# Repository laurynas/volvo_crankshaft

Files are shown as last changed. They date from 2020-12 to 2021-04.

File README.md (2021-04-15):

# Volvo V50 RTI + Crankshaft + Raspberry Pi + Arduino = ❤️

Run Android Auto on Volvo V50 RTI screen by retrofitting it with Raspberry Pi & [Crankshaft](https://getcrankshaft.com/).

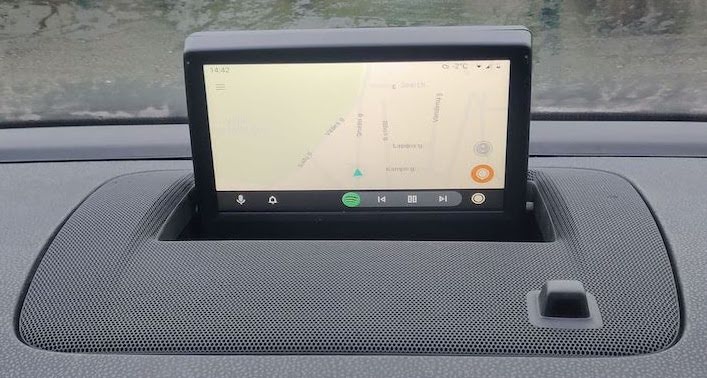
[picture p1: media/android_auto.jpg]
Working example (https://photos.app.goo.gl/vtM3ymQ5z1pJNeDw8)


[Photos and videos »](https://photos.app.goo.gl/vtM3ymQ5z1pJNeDw8)

## Features

- Steering wheel controls
- Open/close display when Android phone is plugged/unplugged

Missing / TODO:

- Automatic brightness adjustment using light sensor
- Sound output to the car stereo via RPi
- Microphone

I'm playing audio via Bluetooh audio adapter. 

## Ingredients

- Volvo V50
- Raspberry Pi 3B or later
- Arduino Pro Micro
- 6.5" AT065TN14 800x480 LCD + driver board. AT065TN14 exactly matches original RTI display dimentions (width x height). Also I found some alternatives - [thinner screen](https://www.aliexpress.com/item/4000329488912.html?spm=a2g0s.9042311.0.0.439c4c4dvR4vq8) and [smaller driver board with audio output](https://www.aliexpress.com/item/4001175095149.html?spm=a2g0s.9042311.0.0.439c4c4dvR4vq8).
- MCP2004 LIN bus transceiver. Or compatible like MCP2003, MCP2025.
- 12V -> 5V step down converter, like XL4005 or LM2596. I would choose 5amps instead of 3amps.
- [HDMI slim flat FPC cable](https://amzn.to/3hjNZCM)
- USB extension cable
- Micro USB to USB cable

## Overview

This is just a rough scheme showing how main components are connected. 

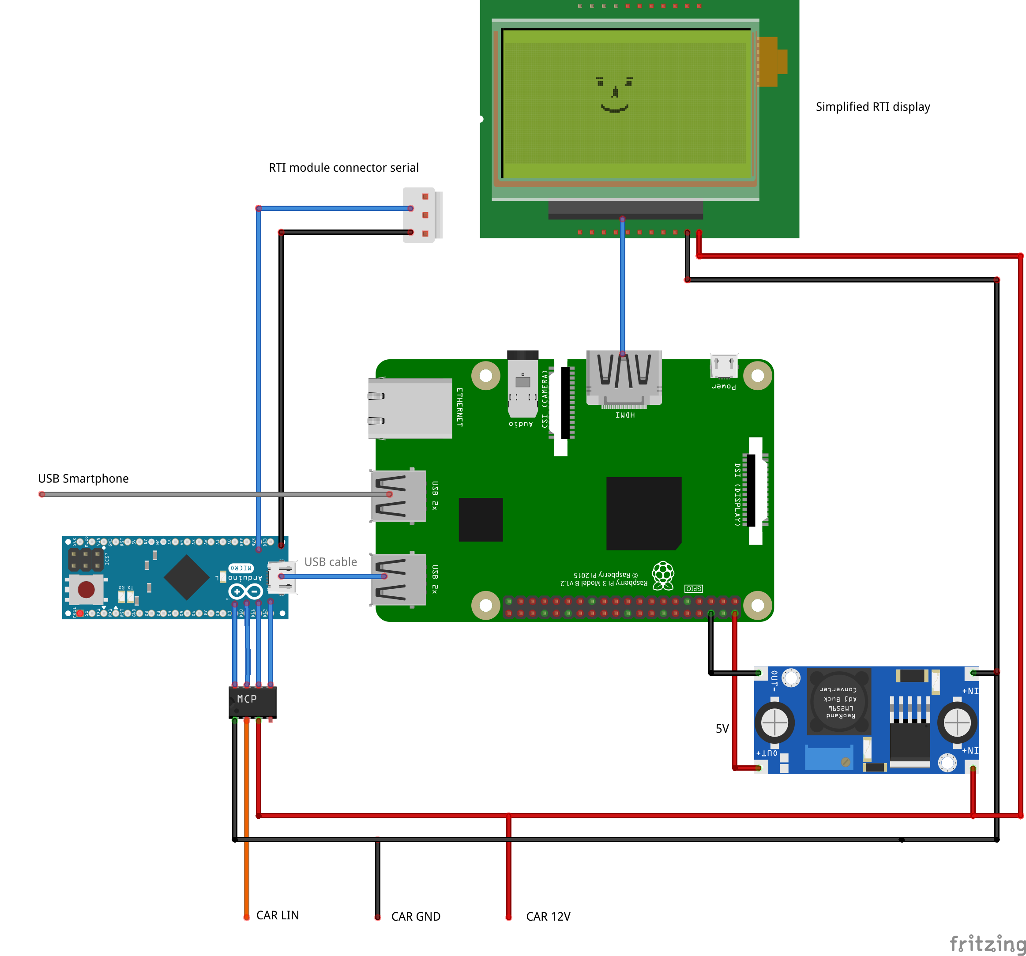
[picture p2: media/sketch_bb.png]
Rough scheme


Raspberry Pi is running [Crankshaft](https://getcrankshaft.com/) which enables Android Auto support.

Arduino is listening for steering wheel button events via [LIN bus](https://github.com/laurynas/volvo_linbus) transceiver. It converts these events to keyboard / mouse HID events and sends to Raspberry Pi via USB. Make sure you are using Arduino [hardware supported by the HID library](https://github.com/NicoHood/HID).

Via the same USB cable Raspberry Pi is sending phone state to Arduino.

Arduino is sending [serial events](https://github.com/laurynas/volvo#screen-control-signal) to Volvo RTI screen module and controls opening / closing of the screen.

Original RTI screen is replaced with AT065TN14 and connected to RPi using HDMI cable. Driver board is powered by 12V from RTI screen module.

RPi is powered from step down converter which converts 12V from the car to 5V.

## Configure Arduino

Build and upload [volvo_crankshaft.ino](volvo_crankshaft.ino) to Arduino.

## Configure RPi / Crankshaft

1. Connect to Crankshaft via [SSH](https://github.com/opencardev/crankshaft/wiki/Crankshaft-dev-mode).
2. Unlock readonly Crankshaft filesystem using `csmt` command line utility.
3. Copy files from [crankshaft/](crankshaft/) to RPi using SSH or just create them via the terminal. Place files under appropriate system folders and make `/opt/service_volvo_crankshaft.sh` executable.
4. Enable the serial service:

> systemctl enable volvo_crankshaft

> systemctl start volvo_crankshaft 

### Configure Crankshaft

Configure Crankshaft using Crankshaft UI -> Settings.

1. Enable keyboard controls - Arduino works as "keyboard" sending keyboard events to RPi.
2. Disable audio if you are playing audio via bluetooth adapter.

## Controls

1. When Android phone is connected, RTI screen should pop automatically and streering wheel controls can be used to navigate Android auto.
2. Clicking "Enter" on the steering wheel buttons when Android phone is disconneted will pop RTI screen and joystic will work as a mouse to navigate Crankshaft UI (you can use it to go to the settings). 
3. Long press of "Back" button will put the screen down.

## Tips

- MMM module is still receiving SWM events and occasionally might speak someting on your audio system :) To avoid that, you can disconnect it, but you need to put [optical bypass](https://allegro.pl/oferta/petla-swiatlowod-most-kabel-audi-seat-skoda-zestaw-9688273368) because otherwise radio wouldn't work. 

## Alternative - Using original RTI LCD display

I have also succeeded using original LCD display too. [More details in the wiki »](https://github.com/laurynas/volvo_crankshaft/wiki/Using-original-RTI-LCD-display).

## Links

- [Volvo V50 LIN bus reader](https://github.com/laurynas/volvo_linbus) - reading steering wheel controls
- [Volvo V50 RTI screen with Arduino controls](https://github.com/laurynas/volvo) - sending serial + VGA signals to original RTI screen
- [Volvo V50 RTI screen removal](https://www.youtube.com/watch?v=MJirMelq5ys)
- [Volvo V50 waterfall panel/radio removal](https://www.youtube.com/watch?v=Xo5NpBt04qs)
- [Volvo V50 glove box removal](https://www.youtube.com/watch?v=bLI-HLhO0_c) - if you decide to remove MMM module
- [Luuk Android Auto RTI project](https://luuk.cc/p/vD2f/Android_Auto_on_Volvo_RTI) - for Volvo S60, S80, V70, etc.

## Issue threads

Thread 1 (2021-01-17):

Volvo S80 2008

jmlgo, 2021-01-17:
Hi there!
First of all, congratulations for your great work! There are no so much options out there for our Volvos with RTI.
I would like to integrate this in my Volvo S80 II from 2008, that equips a DVD-based RTI system. I thinks is pretty similar to your V50 RTI.
I have a couple of doubts:

- Where is the most accesible LIN connector?
- Do you have a more detailed schematic?
- Do you think is it feasible to get rid of the Arduino?

Raspberry Pi has 2 available UARTs and multiple GPIOs, so it's possible to communicate with a external transceiver. The RTI module can be controlled as well, and the keyboard/mouse events can be emulated in python, for example, or can be even included in crankshaft directly (I have to check the sources).

Regards!

laurynas, 2021-01-18:
Hey @jmlgo,

Thanks, glad you liked the project!

I believe S80 has the same RTI screen, it just doesn't fold. I think same screen [replacement](https://www.aliexpress.com/item/4000329488912.html?spm=a2g0s.9042311.0.0.439c4c4dvR4vq8) should fit. I have recently found also a [smaller driver board](https://www.aliexpress.com/item/4001175095149.html?spm=a2g0s.9042311.0.0.439c4c4dvR4vq8) for the screen and it has audio output, which you might find useful.

Regarding LIN bus - I used the wire [from the ICM module](https://github.com/laurynas/volvo_linbus).

I'm just not sure if S80 also uses LIN bus for SWM (steering wheel) signals. There is [a project with S80](https://wot.lv/raspberrypi-powered-car-pc.html) by Latvian guy [Reinis](https://github.com/festlv). He used RPi to retrofit S80 RTI screen and he used CAN bus. Actually it took me quite a while and a lot of CAN bus sniffing until I realised that SWM uses LIN bus instead of CAN bus on my Volvo V50.

I haven't tried to go without Arduino as I reused it from the older project, but it would be nice to do without it. I think you would need 2 serial signals - 1 to send to RTI module, to lift the screen up, and second to talk to CAN bus. Or you can use some CAN header.

Let me know if you would succeed only with RPi, without Arduino. The less components - the better :)

Cheers!
Laurynas

laurynas, 2021-01-18:
Actually I have just checked S80 07- specs on Vida and seems that ICM is talking to SWM via LIN bus (just like V50).
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

Apparently old S80 version (till -06) used CAN bus for SWM.

jmlgo, 2021-01-18:
Thanks for the info!

Good find that driver board, there isn't too much space in my RTI display to fit new electronics.
I've checked Reinis project, and since he is using the previous version of S80 (P2), and I have the more recent P3, SWM will talk through LIN bus as well.

jmlgo, 2021-01-18:
Seems we were commenting at the same time haha
I've checked as well in VIDA with my VIN and indeed, it's talking through LIN bus.

I'll begin soon with this project and I'll try to get rid of the Arduino board to integrate everything with the Raspberry Pi and a external transceiver. I'll be back with an update when I get the parts and can begin with the firsts tests.

Crankshaft and your project are excellent work. There are almost no afordable options for our cars out there to integrate a moderm solution, and even less to do it with Android Auto. Hope I can contribute with some new features.
Regards!

laurynas, 2021-01-18:
Cool! Good luck with your project and let me if you will be able to get rid of Arduino :)

Pabiloboss, 2022-06-07:
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

Hi @jmlgo
I´m wondering if you finally finished your project. I also own an S80 P3 (2011) and having some issues with the low speed can bus for the RTI movement. I monitored that bus and guessed RTI´s ID is 0x07A and have the proper data for raising, stand by, reverse, etc, but when I start throwing those codes in a can bus with just the RTI and my mcp2515 module nothing happens. My module sends the messages correctly, RTI reacts to the can bus (short noise when plugging, like in the car), volts are good (2.7 H and 2.3 L) but RTI do nothing.

Any comment would be more than appreciated!

jmlgo, 2022-06-07:
Hi @Pabiloboss,
I couldn't go ahead with the project at that time due to problems with a faulty screen that I got on Aliexpress.
I had all the setup working over the table with the LIN bus for the SWM, but I never removed the front display from the car so I've never tested the rising command.

Did you got the can-bus frames that the display receives during the normal operation, since you turn on the contact?
Maybe it just needs an init command before the rising command.
I'd be glad if you share that can-bus frames.

Another posibility, since you say it seems to react to the rising command, is that you are not providing enough power to rise the display.

Pabiloboss, 2022-06-07:
@jmlgo , yes I have all can frames and have 2 ids "reacting" when I press enter on the SWM. Also have lin frames, the only thing I'm missing is how to move the screen.
I'm out now but as soon as I arrive home I'll get in touch with you.
So glad we can collaborate!

Pabiloboss, 2022-06-08:
@jmlgo there is no private messaging(I forgot), so give me your email and we can share what we both have and luckily we can create a new repository with the finished job

pavlickk, 2022-08-30:
hello!
any idea, what does it take to control the screen on P3?
ive tried arduino with attached code, but nothing happens

jmlgo, 2022-08-30:
P3 has a low-speed can-bus dedicated for some systems, including the front display.
@Pabiloboss is currently trying to implement this.

AdoDyzas, 2024-03-18:
Hi everybody,

I have RTI P3 from XC70. But can't find any info about how to control RTI display (turn on and rise). As I figure out that all communication goes via CAN communication.  Maybe anyone figure out it? I new with programing so it's not so easy for me.

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

Miziol, 2024-09-19:
Dear @y0grt @Pabiloboss have you got some info about CAN bus command which can open and close the screen?

@AdoDyzas may be you found some info about CAN bus which can help us

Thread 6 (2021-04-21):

Without Steering wheel controls

DaveH240180, 2021-04-21:
Hi Laurynas,

I have came across your build while searching for this exact crankshaft type build, I came across one that didn't really say much with regards to where you place certain code yours is much more informative

My question is this is there any way to modify the code so i dont have the SWC options as the screen i am going to be using has touchscreen functionality, I have a rpi 3b+ and a arduino nano also the latest version of crankshaft all up and running just waiting on a screen to arrive as i am retrofitting a screen into the car as it didn't come with navigation

Any help on this would be greatly appreciated

thanks
Dave

laurynas, 2021-04-28:
Hi Dave,

you you don't need steering wheel controls and use touchscreen instead, it should just work. Actually you could drop Arduino & LIN bus transceiver in this case. You could just send serial signal from RPi to the RTI screen when you would need to raise the screen.

So, you wouldn't need Arduino part at all in this case, but you would need to implement serial signal sending on RPi.

Cheers!
Laurynas

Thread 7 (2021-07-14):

Wiring

tequitotortilla, 2021-07-14:
Hi Laurynas!

Such a great project, it has been great so far!
I'm currently wiring up my pro micro to everything. I already tested it and had the same results as shown in your YT video where you can see the screen getting up. With that project, the RTI is connected using the Tx pin of the pro micro. (had to swap serial with serial1 because I cheaped out and did not get the Arduino version).
Now when looking at the .ino file in this repo I get a little confused; please correct met if i am wrong.
I deduct from the code that the RTI display is now wired via pin 10 with ground still to ground.
Now I think the MCP2003 Rxd pin should be connected to the Pro Micro Tx pin.
And the MCP Txd pin should be connected to the Pro Micro Rx pin.
MCP2003 CS pin to 15 and with no FAULT pin on the 2003, I think pin 17 (RX led) is not connected.
Wiring the Pi directly to acc power in the car is a bad idea since you will be pulling the plug instead of a graceful shutdown. I see in the .ino script that you have implemented a Pi power button too. Which I assume turns the Pi on and off so it can stay wired to the battery 12V. I am not sure how this is connected to the Pi? I was hoping you could help me out here.
I will wire the screen driver board to acc power since it does not need to be powered when the car is off.

Thank you for sharing this amazing project for everyone. Kind regards from Amsterdam,
Niels

tequitotortilla, 2021-07-20:
Update:
I've connected everything up and installed it in the car. Unfortunately the steering wheel buttons are not working. I've wired my MCP2003
Vbb -> 12v
Vss -> ground
Lbus -> Car lin bus (pin 2 from media system)
CS -> 5v powered pin on the arduino
Rx -> arduino Tx
Tx -> arduino Rx

If I understand the documentation of the mcp correctly this should be working.

laurynas, 2021-07-29:
Hi @tequitotortilla, sorry for delayed answer.

The pin numbers are configured in the arduino source code:
https://github.com/laurynas/volvo_crankshaft/blob/main/volvo_crankshaft.ino#L17

You can also try the this simple debugger:
https://github.com/laurynas/volvo_linbus

I was doing my project on Volvo V50, I'm not sure if all models use the same codes. I think other models, like S80 uses CAN-Bus for steering wheel buttons: https://luuk.cc/p/vD2f/Android_Auto_on_Volvo_RTI

Erik187v, 2022-02-01:
Wiring the Pi directly to acc power in the car is a bad idea since you will be pulling the plug instead of a graceful shutdown. I see in the .ino script that you have implemented a Pi power button too. Which I assume turns the Pi on and off so it can stay wired to the battery 12V. I am not sure how this is connected to the Pi? I was hoping you could help me out here. When the Pi is shut off is will not give power to usb (right?) so how is the Pro Micro powered to receive the signal to turn the Pi on? I will wire the screen driver board to acc power since it does not need to be powered when the car is off.

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

Did you solve how the power to the rpi and arduino is controlled?

From what i can tell the arduino starts and shutsdown the rpi on ignition but i have the same question as you do, if the arduino is powered by the rpi how does it start the pie?

what am i missing?

kind regards

tequitotortilla, 2022-02-01:
Hi Erik, I did solve the issue in the end by just shutting down the power on the RPi with the ignition. It is not very graceful but in one of the processes the RPi was set to only read not write on storage. If systems get corrupted with ungraceful shutdowns it is mostly because the system was interrupted while (re)writing system files. Because the system is read only that does not happen and it reduces the chance of a corrupted system. Mine is stull running after 6 months at least. Although I never got the steering wheel buttons to work :(

Lukasguy, 2022-02-08:
Did you ever try connecting the Rxd pin of the MCP to the Rx input of the arduino? Rxd stands for Rxdevice (I think) and according to the datasheet it's an output. Thus Rxd has to be connected to Rx and Txd has to be connected to Tx (which is confusing because normally it's the other way around). The typical applications section 1.4 also shows this. I would test & verify this myself but I'm still in the testbench phase, though I will run into this later.

Also thank you Laurynas for this project! It has been a huge inspiration for me to integrate Carplay into my C30!

Erik187v, 2022-04-12:
> Hi Erik, I did solve the issue in the end by just shutting down the power on the RPi with the ignition. It is not very graceful but in one of the processes the RPi was set to only read not write on storage. If systems get corrupted with ungraceful shutdowns it is mostly because the system was interrupted while (re)writing system files. Because the system is read only that does not happen and it reduces the chance of a corrupted system. Mine is stull running after 6 months at least. Although I never got the steering wheel buttons to work :(

Its figured it out, he left out the transistor and some resistors acting as a power switch,  shorting pin 5 and 6 to turn on the PI when its off and using a shutdown script turning it off gracefully with the pin is high (stays low when ignition is on because the pins is shorted). I used a BC574 and 2x 1k ohm resistors to act as a switch. instead of using the output from the arduino you could hook it upp directly to the cars ignition as i did with a regulator in between!

Script example shutdown after 15min when iginition goes off and cancel if it goes on before (I did some modifications where i turn off the LCD directly and on again if ignition goes live so if i stop for gas i dont have to wait for the pi to boot).
#! /usr/bin/env python

import time
import RPi.GPIO as GPIO
import subprocess
GPIO.setmode(GPIO.BCM)
GPIO.setwarnings(False)

pin = 3 // pin 5  is gpio 3

GPIO.setup(pin, GPIO.IN, GPIO.PUD_UP)

while True:
    button_state = GPIO.input(pin)
    if button_state == GPIO.HIGH:
      subprocess.call(['shutdown', '-h', '15'], shell=False)
      print ("Ignition off")
    else:
      subprocess.call(['shutdown', '-c'], shell=False)
      print ("Ignition on")
    time.sleep(5)

Regulator 12v -> 5v:
https://www.amazon.se/ARCELI-AMS1117-3-3-sp%C3%A4nningsregulator-avst%C3%A4ngningsbar-str%C3%B6mf%C3%B6rs%C3%B6rjningsbuljong/dp/B07MY2NMQ6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

Erik187v, 2022-04-12:
> Did you ever try connecting the Rxd pin of the MCP to the Rx input of the arduino? Rxd stands for Rxdevice (I think) and according to the datasheet it's an output. Thus Rxd has to be connected to Rx and Txd has to be connected to Tx (which is confusing because normally it's the other way around). The typical applications section 1.4 also shows this. I would test & verify this myself but I'm still in the testbench phase, though I will run into this later.
>
> Also thank you Laurynas for this project! It has been a huge inspiration for me to integrate Carplay into my C30!

Im also installing Carplay on my C30 using Open Auto. But the biggest problem for us is that we need to keep the original LCD! But not anymore, hit me up if u want the option to stream the ICM instead, i'd be happy to help out!

Bye bye crappy LCD :
https://www.youtube.com/shorts/r7sB46zHM6A

laurynas, 2022-04-13:
Hey, sorry, missed most of the discussion :) Just my 5 cents - I'm using my solution almost daily. There is no graceful shutdown, just the hard power off. Works fine for more than a year.. :)
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
Erik187v, 2022-05-17:
I dont use the rti part since i replaced the original icm so i cant help with that in sorry.

as long as the wires are right u could debug with any linbus reader. There is plenty out there with better support! As long as u have it reading linbus u can work on the software for the keyboard ur self. Its the best way to tackle this. I decided to use another linbus frame and built my kerboard handeler my self and just skipped the rti part.

but to make it easier for u i would suggest that. Try another clean linbus reader slave source and build upon that instead

Pabiloboss, 2022-05-17:
> I dont use the rti part since i replaced the original icm so i cant help with that in sorry.
>
> as long as the wires are right u could debug with any linbus reader. There is plenty out there with better support! As long as u have it reading linbus u can work on the software for the keyboard ur self. Its the best way

Erik187v, 2022-05-18:
> > I dont use the rti part since i replaced the original icm so i cant help with that in sorry.
>
> That's dreat! That was my first idea, to replace the icm, but I have the premium sound system which is dawm good but, unluckily, all configurations go through the original icm, so I ended up just replacing the Navi...

I still use the original amplifier and i kept the icm module ans hijack the lcd signal and display it as a overlay on my setup. I can still use the original configuration and menus i just dont have the old lcd

Pabiloboss, 2022-05-18:
> I still use the original amplifier and i kept the icm module ans hijack the lcd signal and display it as a overlay on my setup. I can still use the original configuration and menus i just dont have the old lcd
>
> https://youtu.be/h19fsgQmMdM

Simply amazing! Great job! I look forward to seeing your progress! Even though it´s not my goal (I rather like navi on top of the dashboard), if you´d like to test your project on a S80 P3 just let me know. I´m more than willing to collaborate, @Erik187v

Pabiloboss, 2022-05-24:
Guys, I had the suspicion, but now I´m sure. In P3 configuration, at least my S80´s, rti screen is managed via low speed CAN BUS. I've been through VIDA and it is crystal clear. So now I´ll make my own research and CAN sniff so I can modify laurynas code accordingly. I´ll let you know when sorted out.

jacoqq, 2025-03-30:
Hi,
First of all, thank You Laurynas, great job.
I'm stiil confused with wiring. Is there anyone who could make a sketch with the exact connection? According to https://photos.google.com/share/AF1QipMlcIAPwL2aJV3OyTbHpNdbMLiskVYX2OP57K1AqoD92cU2QgqgX4AXHpQ2rx2HcA/photo/AF1QipMFsHBVfw-tWltWxdz219b_BTAqYg37RJw1u_JB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 there are a few more resistors and I have no idea how to connect it all together.
I would be extremely grateful for some guidance.
My spec:
Volvo S40
RPi 3 B+
Arduino Pro Micro (Leonardo)
MCP 2004A-E/P

laurynas, 2025-04-01:
Hey @jacoqq ,

I'm glad you find this project useful and doing DIY yourself 👍 Unfortunately I already sold my Volvo so I don't remember exact wiring, but the rough idea (without exact pins) I've described here:
https://github.com/laurynas/volvo_crankshaft?tab=readme-ov-file#overview
also this could be useful, just to understand MCP first, before building full solution:
https://github.com/laurynas/volvo_linbus

I agree that in the photo you referenced, there are more components visible, like a button and transistor. I think I used it for raspberry pi power button via GPIO:
https://github.com/laurynas/volvo_crankshaft/blob/main/volvo_crankshaft.ino#L22
I think the physical button is not needed, I probably just used it for testing.

Sorry, I don't remember in more details, but I think from this rough charts it should be possible to build a working solution (it was working and I used it for years). Just experiment with MCP connecting it to Arduino first via serial, and also experiment with the screen mechanism connecting it via serial. It takes some time to figure out, but once you do - everything should become quite simple.

jacoqq, 2025-04-04:
That explain me a lot and now everything seems to be clear. I'm still waiting for my MCP and after that I'm getting down to work. Again thanks Laurynas, I owe You a huge beer :)

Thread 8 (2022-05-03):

Arduino - class LinFrame 'pop_byte' error

cavewd, 2022-05-03:
Hi! i have been following your page to this project myself and it has been very helpful. I'm new to both raspberry and Arduino, but i have not been able to fix this error through using your write up. I'm really hoping you'll be able to help me

I'm running IDE version 1.8.19, i have tried restarting building the .ino file twice but keep getting to this error, i feel like i might be missing a .h file or another library as IDE is not colouring all the code like it is seen on github.
sorry for making another issue, your work has been very helpful (i am absolutely a Linux/C noob!) but i cant get around this error
thanks for your time

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
e

Lukasguy, 2022-05-06:
Hi,  not the creator of this project but maybe I can help.

In the pictures you posted I can't see the include for lin_frame.h: #include "src/lin_frame.h"
This is very important, otherwise lin_frame class and it's functions can not be found.

I was also wondering why the SoftwareSerial.h file is in the same folder as the .ino file. If your arduino IDE can not find the software serial library then you should install it using the library manager from the IDE:
https://docs.arduino.cc/software/ide-v1/tutorials/installing-libraries

Perhaps you should start from the original .ino first and test if everything works. Then start modifying it to add whatever you need.

Good luck!

cavewd, 2022-05-09:
Hi All. this was an error on my part for being new to github!
i had copied the code in each file trying to replicate Laurynas work, when i should have downloaded it as a zip and then run the .ino file. There is no issue with the project.
For people like me with no experience:
Make sure to find the correct software for the pro micro board(Sparkfun pro micro) online and add to the arduino coding environment, you wont find the right board without it. Similarly, make sure the cable used will transfer data not just power else you'll never find the right port or upload to the board.
If you're new to Linux, make sure to look up Linux file system hierarchy as its useful when navigating to the correct file area for crankshaft install, how to enter terminal on crankshaft (dev mode) and commands like: cd, ls (LS), gitclone, rasp config, chmod -x. Use a raspberry pi software loader to put crankshaft on your pi, loads of videos online for this.
and a thank you to Lukasguy, your comment about the original .ino file meant i realised where i had gone very wrong :))

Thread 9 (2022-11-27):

Only steering buttons

OziMasterPL, 2022-11-27:
Thank You for this project.
I have Openauto Pro not Crankshaft
I need use arduino only for  steering buttons emulation without mouse mode and open/close rti screen.
How modify code for this.

How do it?

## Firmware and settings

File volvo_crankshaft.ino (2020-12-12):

//Lbus = LIN BUS from Car
//Vss = Ground
//Vbb = +12V

// MCP2004 LIN bus frame:
// ZERO_BYTE SYN_BYTE ID_BYTE DATA_BYTES.. CHECKSUM_BYTE

#define DEBUG true

#include "Keyboard.h"
#include "Mouse.h"
#include "SoftwareSerial.h"

// https://github.com/zapta/linbus/tree/master/analyzer/arduino
#include "src/lin_frame.h"

#define CS_PIN 15
#define RX_LED 17
#define RTI_RX_PIN 16
#define RTI_TX_PIN 10

#define PI_POWER_BUTTON_PIN A3
#define PI_POWER_BUTTON_DURATION 100
#define PI_TIMEOUT 30000

#define ON_CLICK_DURATION 100
#define OFF_CLICK_DURATION 3000 // how long to hold "back" button to turn off

#define CLICK_TIMEOUT 300

#define HEARTBEAT_TIMEOUT 2000
#define RTI_INTERVAL 100

#define MOUSE_BASE_SPEED 8
#define MOUSE_SPEEDUP 3

#define SYN_FIELD 0x55
#define SWM_ID 0x20

// Volvo V50 2007 SWM key codes
//
// BTN_NEXT       20 0 10 0 0 EF
// BTN_PREV       20 0 2 0 0 FD
// BTN_VOL_UP     20 0 0 1 0 FE
// BTN_VOL_DOWN   20 0 80 0 0 7F
// BTN_BACK       20 0 1 0 0 F7
// BTN_ENTER      20 0 8 0 0 FE
// BTN_UP         20 1 0 0 0 FE
// BTN_DOWN       20 2 0 0 0 FD
// BTN_LEFT       20 4 0 0 0 FB
// BTN_RIGHT      20 8 0 0 0 F7
// IGN_KEY_ON     50 E 0 F1

#define JOYSTICK_UP 0x1
#define JOYSTICK_DOWN 0x2
#define JOYSTICK_LEFT 0x4
#define JOYSTICK_RIGHT 0x8
#define BUTTON_BACK 0x1
#define BUTTON_ENTER 0x8
#define BUTTON_NEXT 0x10
#define BUTTON_PREV 0x2

#define CRANKSHAFT_ANDROID_CONNECTED '+'
#define CRANKSHAFT_ANDROID_DISCONNECTED '-'

short rtiStep;

SoftwareSerial rtiSerial(RTI_RX_PIN, RTI_TX_PIN);

LinFrame frame = LinFrame();

unsigned long currentMillis, lastHeartbeat, lastPiHeartbeat, lastRtiWrite, buttonDownAt, lastButtonAt, lastJoysticButtonAt;
bool on = false;
bool android = false;
bool manualOn = false;
byte currentButton, currentJoystickButton;
int mouseSpeed = MOUSE_BASE_SPEED;

void setup() {
  pinMode(PI_POWER_BUTTON_PIN, OUTPUT);
  analogWrite(PI_POWER_BUTTON_PIN, 0);

  pinMode(RX_LED, OUTPUT);

  pinMode(CS_PIN, OUTPUT);
  digitalWrite(CS_PIN, HIGH);

  Serial.begin(9600);
  Serial1.begin(9600);
  rtiSerial.begin(2400);

  Keyboard.begin();

  //turn_on();
  disable_android_mode();
}

void loop() {
  currentMillis = millis();

  if (Serial.available())
    read_crankshaft();

  if (Serial1.available())
    read_lin_bus();

  timeout_button();
  check_ignition_key();
  rti();
  power_on_pi();
}

void read_crankshaft() {
  byte b = Serial.read();

  lastPiHeartbeat = currentMillis;

  switch (b) {
    case CRANKSHAFT_ANDROID_CONNECTED:
      if (!on) turn_on();
      if (!android) enable_android_mode();
      break;

    case CRANKSHAFT_ANDROID_DISCONNECTED:
      if (on && !manualOn) turn_off();
      break;
  }

  if (DEBUG) {
    Serial.println(b);
//    Keyboard.write(b);
    Serial.println(is_ignition_off() ? "RESPONSE: CMD SHUTDOWN" : "RESPONSE: OK");
  } else {
    Serial.println(is_ignition_off() ? "CMD SHUTDOWN" : "OK");    
  }
}

void read_lin_bus() {
  byte b = Serial1.read();
  int n = frame.num_bytes();

  if (b == SYN_FIELD && n > 2 && frame.get_byte(n - 1) == 0) {
    digitalWrite(RX_LED, LOW);

    frame.pop_byte();
    handle_swm_frame();
    frame.reset();

    digitalWrite(RX_LED, HIGH);
  } else if (n == LinFrame::kMaxBytes) {
    frame.reset();
  } else {
    frame.append_byte(b);
  }
}

void handle_swm_frame() {
  if (frame.get_byte(0) != SWM_ID)
    return;

  lastHeartbeat = currentMillis;

  // skip zero values 20 0 0 0 0 FF
  if (frame.get_byte(5) == 0xFF)
    return;

  if (!frame.isValid())
    return;

  //  dump_frame();
  handle_buttons();
  handle_joystick();
}

void handle_joystick() {
  if (!on) return;

  byte button = frame.get_byte(1);

  timeout_joystic_button();

  if (button != currentJoystickButton) {
    currentJoystickButton = button;
    mouseSpeed = MOUSE_BASE_SPEED;

    if (android) click_joystick(button);
  }

  if (android) return;

  switch (button) {
    case JOYSTICK_UP:
      move_mouse(0, -1);
      break;
    case JOYSTICK_DOWN:
      move_mouse(0, 1);
      break;
    case JOYSTICK_LEFT:
      move_mouse(-1, 0);
      break;
    case JOYSTICK_RIGHT:
      move_mouse(1, 0);
      break;
  }
}

void click_joystick(byte button) {
  switch (button) {
    case JOYSTICK_UP:
      Keyboard.write(KEY_UP_ARROW);
      debug("UP");
      break;
    case JOYSTICK_DOWN:
      Keyboard.write(KEY_DOWN_ARROW);
      debug("DOWN");
      break;
    case JOYSTICK_LEFT:
      Keyboard.write('1');
      debug("LEFT");
      break;
    case JOYSTICK_RIGHT:
      Keyboard.write('2');
      debug("RIGHT");
      break;
  }

  lastJoysticButtonAt = currentMillis;
}

void timeout_joystic_button() {
  if (!currentJoystickButton)
    return;

  if (since(lastJoysticButtonAt) > CLICK_TIMEOUT)
    currentJoystickButton = 0;
}

void move_mouse(int dx, int dy) {
  Mouse.move(dx * mouseSpeed, dy * mouseSpeed, 0);
  mouseSpeed += MOUSE_SPEEDUP;
}

void handle_buttons() {
  byte button = frame.get_byte(2);

  if (!button)
    return;

  if (button != currentButton) {
    release_button(currentButton, since(buttonDownAt));
    click_button(button);

    currentButton = button;
    buttonDownAt = currentMillis;
  }

  lastButtonAt = currentMillis;
}

void click_button(byte button) {
  if (!on) return;

  switch (button) {
    case BUTTON_ENTER:
      if (android)
        Keyboard.write(KEY_RETURN);
      else 
        Mouse.click();
      debug("ENTER");
      break;
    case BUTTON_BACK:
      Keyboard.write(android ? KEY_ESC : 'H');
      debug("ESC");
      break;
    case BUTTON_PREV:
      Keyboard.write('V');
      debug("PREV");
      break;
    case BUTTON_NEXT:
      Keyboard.write('N');
      debug("NEXT");
      break;
  }
}

void timeout_button() {
  if (!currentButton)
    return;

  if (since(lastButtonAt) > CLICK_TIMEOUT)
    release_button(currentButton, since(buttonDownAt));
}

void release_button(byte button, unsigned long clickDuration) {
  switch (button) {
    case BUTTON_ENTER:
      if (!on && clickDuration > ON_CLICK_DURATION) {
        manualOn = true;
        turn_on();
      }
      break;

    case BUTTON_BACK:
      if (clickDuration > OFF_CLICK_DURATION) {
        manualOn = false;
        turn_off();
      }
      break;
  }

  currentButton = 0;
}

void check_ignition_key() {
  if (lastHeartbeat && is_ignition_off()) {
    debug("Ignition off");
    turn_off();
  }
}

bool is_ignition_off() {
  return since(lastHeartbeat) > HEARTBEAT_TIMEOUT;
}

void turn_on() {
  debug("Turn on");
  on = true;
}

void turn_off() {
  debug("Turn off");
  on = false;
  disable_android_mode();
}

void enable_android_mode() {
  debug("Android on");
  android = true;
  Mouse.end();
}

void disable_android_mode() {
  debug("Android off");
  android = false;
  Mouse.begin();
}

// send serial data to Volvo RTI screen mechanism
void rti() {
  if (since(lastRtiWrite) < RTI_INTERVAL) return;

  switch (rtiStep) {
    case 0: // mode
      rti_print(on ? 0x40 : 0x46);
      debug(on ? "ON" : "OFF");
      debug(android ? "ANDROID ON" : "ANDROID OFF");
      rtiStep++;
      break;

    case 1: // brightness
      rti_print(0x20);
      rtiStep++;
      break;

    case 2: // sync
      rti_print(0x83);
      rtiStep = 0;
      break;
  }

  lastRtiWrite = currentMillis;
}

void rti_print(char byte) {
  rtiSerial.print(byte);
}

void power_on_pi() {
  if (since(lastPiHeartbeat) > PI_TIMEOUT && !is_ignition_off())
    click_pi_power_button();
}

void click_pi_power_button() {
  analogWrite(PI_POWER_BUTTON_PIN, 255);
  delay(PI_POWER_BUTTON_DURATION);
  analogWrite(PI_POWER_BUTTON_PIN, 0);
}

// -- debugging

void dump_frame() {
  for (int i = 0; i < frame.num_bytes(); i++) {
    Serial.print(frame.get_byte(i), HEX);
    Serial.print(" ");
  }
  Serial.println();
}

void debug(String message) {
  if (DEBUG)
    Serial.println(message);
}

long since(long timestamp) {
  return currentMillis - timestamp;
}

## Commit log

2020-11-23 Refactor button handling
2020-11-23 Fix RPi serial listener
    [volvo_crankshaft.ino]
2020-12-12 Adjust wheel controls
2020-12-25 Add scheme
    [sketch.fzz]
2020-12-25 Update scheme
    [sketch.fzz]
2020-12-25 Fix case
2020-12-26 Adjust links
    [sketch.fzz]
2020-12-26 Adjust lines
    [sketch.fzz]
2020-12-26 Add comment about fast charging
